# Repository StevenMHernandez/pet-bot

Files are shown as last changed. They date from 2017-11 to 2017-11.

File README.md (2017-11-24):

# Pet Bot

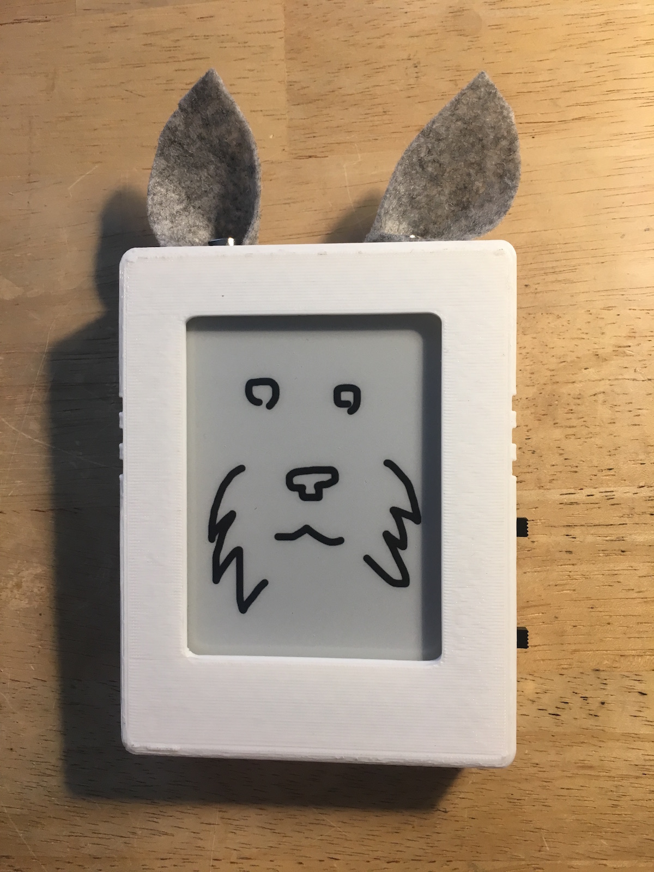
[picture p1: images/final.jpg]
Final pet


IoT connected pet bot connecting an E-ink display to an ESP8266 microcontroller connected through to the AWS IoT service.

Device Shadows are used in AWS IoT to model the ESP8266 when not connected to the network.
When connected, this allows the use of MQTT to transmit message from the server to the device and vice-versa.

Events (created through IFTTT) push data through an API Gateway to an AWS Lambda function to update the Device Shadow (Again through MQTT).

This repository contains:

* [3d models](3d) which were 3d printed in white
* [API Gateway/AWS Lambda functions](aws-lambda) used in the "serverless" backend
* [C++ code](src) used to program the microcontroller
* [Wiring schematics](schematic)
* [SD Card images](sdcard)
* [Network Diagram](network) for the whole system

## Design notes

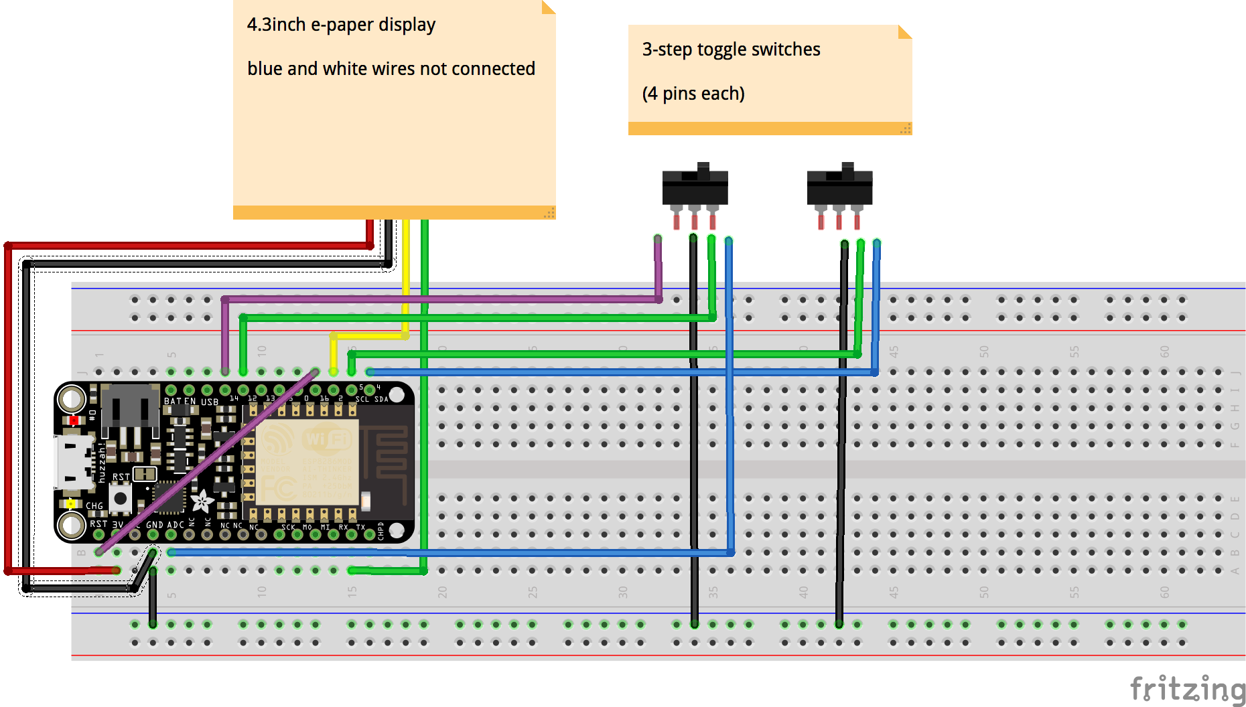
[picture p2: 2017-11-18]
schematic/layout_bb.png

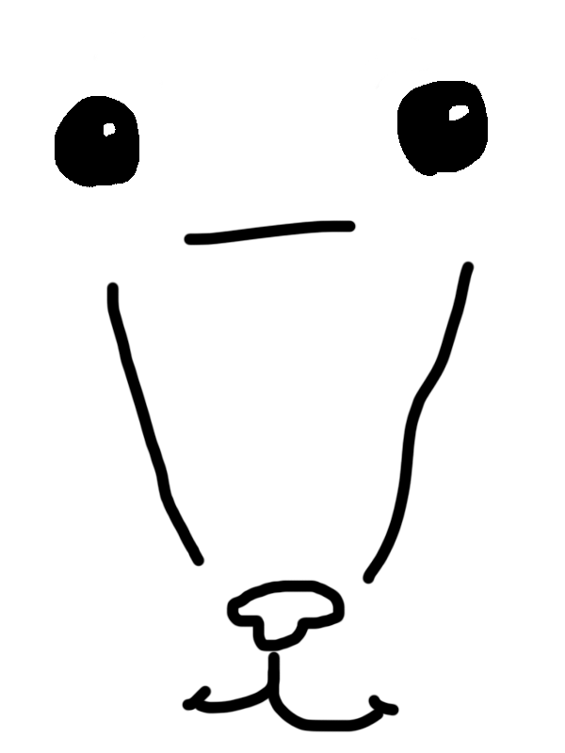
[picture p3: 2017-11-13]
sdcard/DOG20.BMP

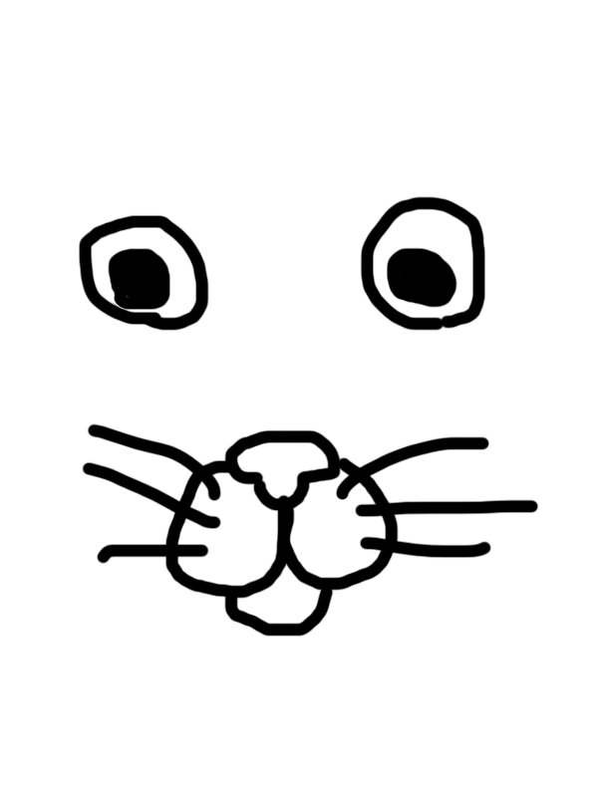
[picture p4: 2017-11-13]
sdcard/CAT00.BMP

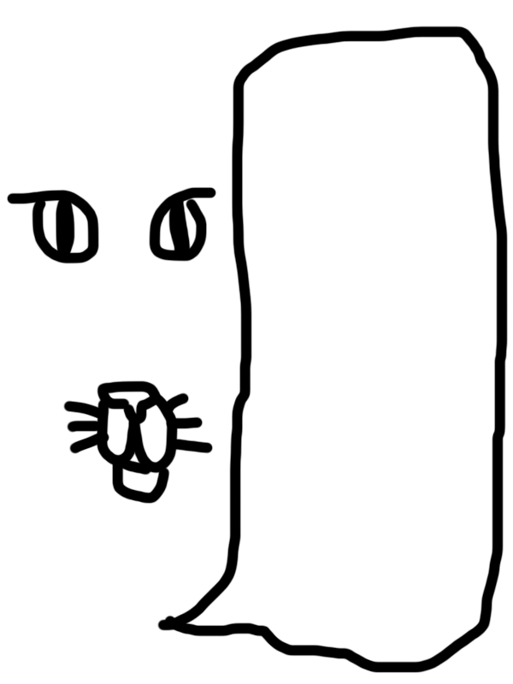
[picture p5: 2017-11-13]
sdcard/CAT11.BMP

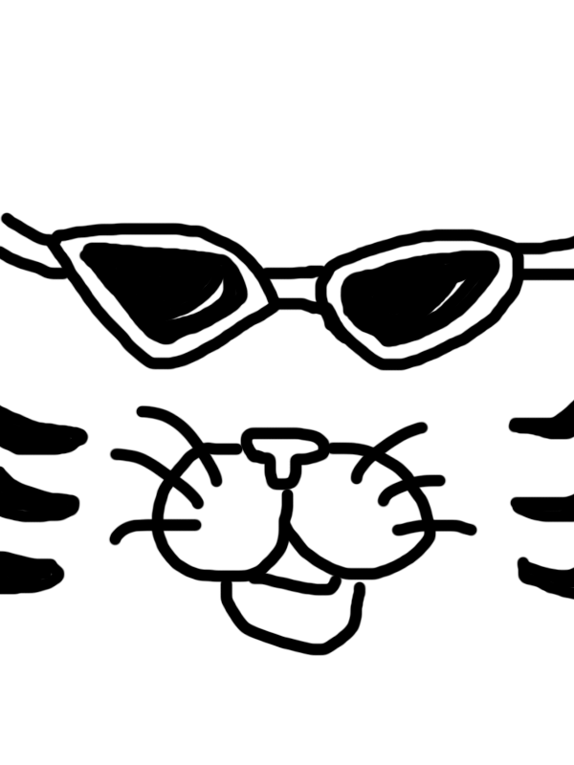
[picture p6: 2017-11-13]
sdcard/CAT20.BMP

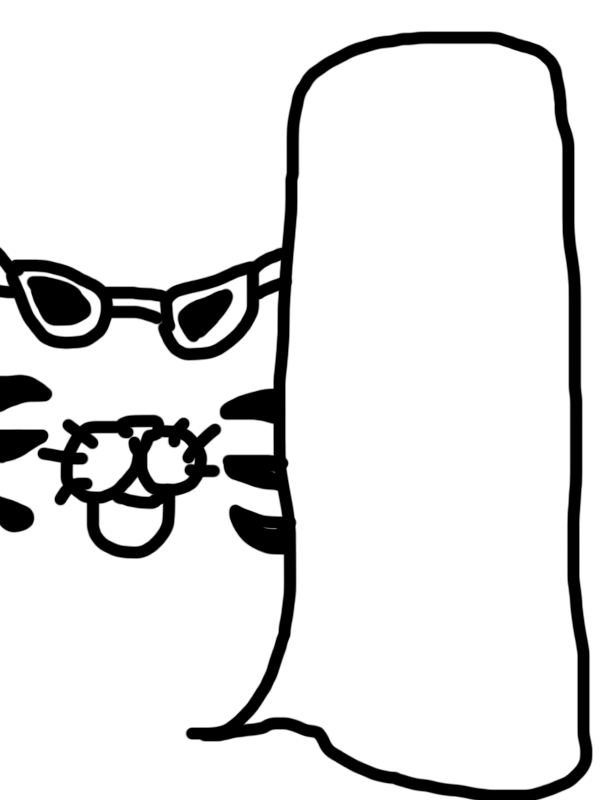
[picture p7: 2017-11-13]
sdcard/CAT21.BMP

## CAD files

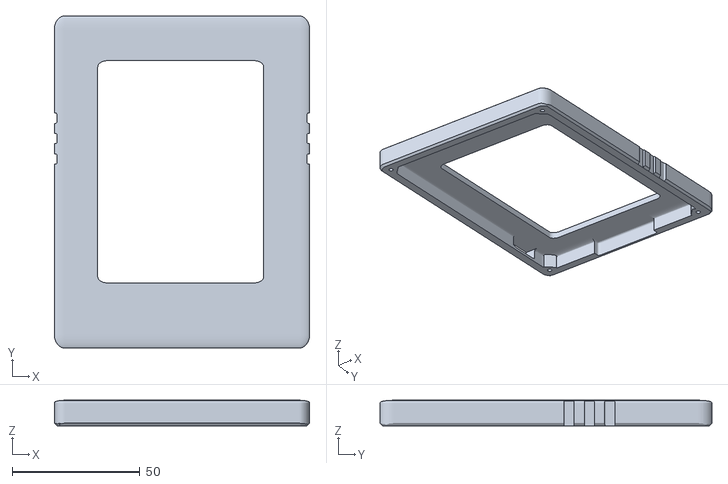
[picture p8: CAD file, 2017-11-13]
3d/front_enclosure.stl
100.0 x 130.0 x 10.00

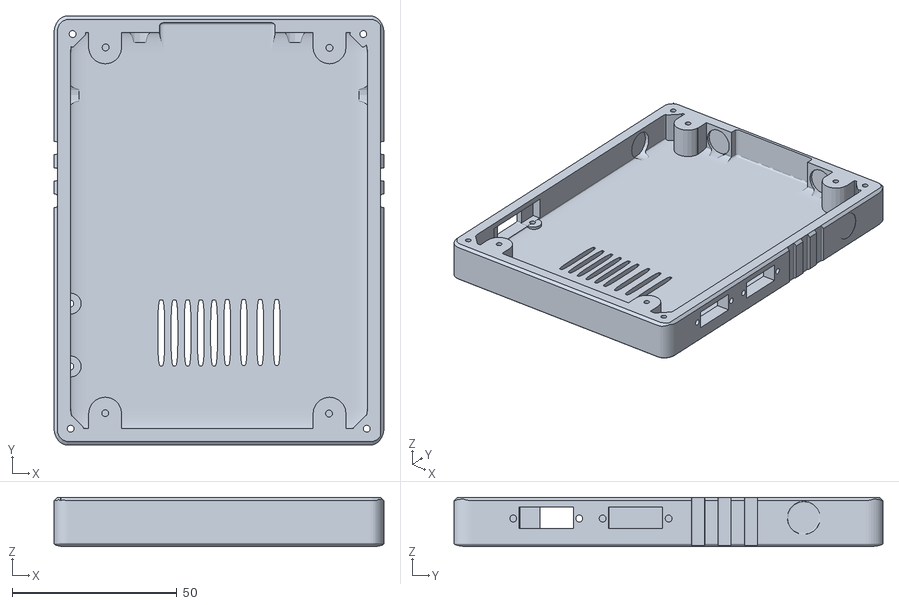
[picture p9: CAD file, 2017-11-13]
3d/back_enclosure.stl
100.0 x 130.0 x 15.0

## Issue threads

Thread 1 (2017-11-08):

Poll for messages

StevenMHernandez, 2017-11-08:
It seems that MQTT may not be a good option here for a battery powered device. There is rarely any new data published or received. Instead, polling will allow for deep sleep to conserve battery power.

StevenMHernandez, 2017-11-18:
Same as #2

Closed 2017-11-18.

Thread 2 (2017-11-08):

Deep sleep

StevenMHernandez, 2017-11-08:
Save power by automatically entering deep sleep mode

StevenMHernandez, 2017-11-16:
Connect pin 16 to reset.
Remove pin 16 connection from toggle switch (it is no longer needed)

Closed 2017-11-16.

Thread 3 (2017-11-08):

Toggles produce interrupts

StevenMHernandez, 2017-11-08:
To wake from sleep mode, we should also have interrupts on the pins used for the toggle switches

StevenMHernandez, 2017-11-16:
Unfortunately only the RESET pin can be used to leave deep sleep mode. Unfortunately, we can't create a simple logic gate with transistors to test for changes in the toggle switches. We are looking for rising edges, not boolean value.

So, we will not have interrupts here. Instead, we will just poll for value changes after leaving deep sleep.

Closed 2017-11-16.

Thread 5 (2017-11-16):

Display updates even when nothing changes after leaving deep sleep

StevenMHernandez, 2017-11-16:
We need to remember the screen values after exiting deep sleep.

`toggleChanged()` seems to be useless because the program resets to make this always evaluate to false.

StevenMHernandez, 2017-11-18:
This will be handled by checking the `delta` value of the device shadow from aws-iot

Closed 2017-11-18.

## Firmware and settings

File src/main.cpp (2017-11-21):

#include "Arduino.h"
#include <ESP8266WiFi.h>
#include <epd.h>
#include <aJSON.h>
#include "config.h"
#include "time.h"
#include "pin_mappings.h"
#include "bitmap_helpers.h"
#include "config/ConnectionParams.h"
#include "aws/ESP8266DateTimeProvider.h"

#define SHADOW_STATUS_REPORTED "reported"
#define SHADOW_STATUS_DESIRED "desired"

const char *AP_SSID = SSID_NAME;
const char *AP_PASS = SSID_PASS;

char *region = (char *) MY_AWS_REGION;
char *endpoint = (char *) MY_AWS_IOT_ENDPOINT;
char *mqttHost = (char *) MY_AWS_IOT_MQTT_HOST;
int mqttPort = MY_AWS_IOT_MQTT_PORT;
char *iamKeyId = (char *) MY_AWS_IAM_KEY_ID;
char *iamSecretKey = (char *) MY_AWS_IAM_SECRET_KEY;

ESP8266DateTimeProvider dtp;
AwsIotSigv4 sigv4(&dtp, region, endpoint, mqttHost, mqttPort, iamKeyId, iamSecretKey);
ConnectionParams cp(sigv4);
WebSocketClientAdapter adapter(cp);
MqttClient client(adapter, cp);

char filename[11];
uint32_t sleepTime = 30; // in minutes

void renderBitmap(int status) {
    epd_clear();
    epd_disp_string("loading...", 240, 750);
    epd_udpate();

    epd_clear();
    buildBitmapFileName(filename, status);
    epd_disp_bitmap(filename, 0, 0);

    if (status == STATUS_NO_MESSAGE) {
        epd_udpate();
    }
}

void setup_pins() {
    pinMode(TYPE_PIN_A, INPUT_PULLUP);
    pinMode(TYPE_PIN_B, INPUT_PULLUP);
    pinMode(TYPE_PIN_C, INPUT_PULLUP);

    pinMode(VARIANT_PIN_B, INPUT_PULLUP);
    pinMode(VARIANT_PIN_C, INPUT_PULLUP);
}

void setup_screen() {
    epd_set_memory(MEM_TF);
    epd_set_color(BLACK, WHITE);
    epd_screen_rotation(EPD_INVERSION);
    epd_set_en_font(GBK32);
}

void enter_sleep_mode(uint32_t minimum_sleep_time) {
    epd_enter_stopmode();
    if (sleepTime > 0) {
        ESP.deepSleep(sleepTime * SECONDS_PER_MINUTE * MICROSECONDS_PER_SECOND);
    } else {
        ESP.deepSleep(minimum_sleep_time);
    }
}

void update_thing_shadow(char *status, char *key, char *value) {
    aJsonObject *rootObj, *stateObj, *reportedObj;
    rootObj = aJson.createObject();
    aJson.addItemToObject(rootObj, "state", stateObj = aJson.createObject());
    aJson.addItemToObject(stateObj, status, reportedObj = aJson.createObject());
    aJson.addStringToObject(reportedObj, key, value);

    char *json = aJson.print(rootObj);
    client.publish("$aws/things/pet-test/shadow/update", json, 0, false);
    free(json);
}

void update_thing_shadow(char *status, char *key, int value) {
    aJsonObject *rootObj, *stateObj, *reportedObj;
    rootObj = aJson.createObject();
    aJson.addItemToObject(rootObj, "state", stateObj = aJson.createObject());
    aJson.addItemToObject(stateObj, status, reportedObj = aJson.createObject());
    aJson.addNumberToObject(reportedObj, key, value);

    char *json = aJson.print(rootObj);
    client.publish("$aws/things/pet-test/shadow/update", json, 0, false);
    free(json);
}

void update_thing_shadow(char *status, char *key, aJsonObject *value) {
    aJsonObject *rootObj, *stateObj, *reportedObj;
    rootObj = aJson.createObject();
    aJson.addItemToObject(rootObj, "state", stateObj = aJson.createObject());
    aJson.addItemToObject(stateObj, status, reportedObj = aJson.createObject());
    aJson.addItemToObject(reportedObj, key, value);

    char *json = aJson.print(rootObj);
    client.publish("$aws/things/pet-test/shadow/update", json, 0, false);
    free(json);
}

void setup_wifi_mqtt() {
    WiFi.begin(AP_SSID, AP_PASS);
    while (WiFi.status() != WL_CONNECTED) {
        delay(500);
    }

    int res = client.connect();

    if (res == 0) {
        update_thing_shadow((char *) SHADOW_STATUS_DESIRED, (char *) "type", getTypeName());
        update_thing_shadow((char *) SHADOW_STATUS_DESIRED, (char *) "variant", getVariantNumber());

        delay(100);

        client.subscribe("$aws/things/pet-test/shadow/get/accepted", 0, [](const char *topic, const char *msg) {
            // parse JSON, if there is a delta, update the screen
            aJsonObject *jsonObject = aJson.parse((char *) msg);
            aJsonObject *stateObject = aJson.getObjectItem(jsonObject, "state");
            aJsonObject *deltaObject = aJson.getObjectItem(stateObject, "delta");
            aJsonObject *desiredObject = aJson.getObjectItem(stateObject, "desired");
            aJsonObject *messageArray = aJson.getObjectItem(desiredObject, "message");
            aJsonObject *sleepTimeObject = aJson.getObjectItem(desiredObject, "sleepTime");
            sleepTime = sleepTimeObject->valueint;

            // Is there a delta? If so, we need to update the display
            // Otherwise, we are fine to sleep
            if (deltaObject != NULL && deltaObject->type != NULL && deltaObject->type == aJson_Object) {
                epd_clear();

                if (messageArray->type == aJson_Array && ((int) aJson.getArraySize(messageArray)) > 0) {
                    renderBitmap(STATUS_HAS_MESSAGE);

                    int totalHeight = 600;
                    int usedHeight = 50 * (int) aJson.getArraySize(messageArray);
                    int paddingTop = 100 + ((totalHeight - usedHeight) / 2);

                    int size = (int) aJson.getArraySize(messageArray);

                    for (int i = 0; i < size; i++) {
                        aJsonObject *m = aJson.getArrayItem(messageArray, (unsigned char) i);
                        epd_disp_string(m->valuestring, 330, paddingTop + (50 * i));
                    }

                    epd_udpate();
                } else {
                    renderBitmap(STATUS_NO_MESSAGE);
                }

                update_thing_shadow((char *) SHADOW_STATUS_REPORTED, (char *) "message", messageArray);
                update_thing_shadow((char *) SHADOW_STATUS_REPORTED, (char *) "type", getTypeName());
                update_thing_shadow((char *) SHADOW_STATUS_REPORTED, (char *) "variant", getVariantNumber());
                update_thing_shadow((char *) SHADOW_STATUS_REPORTED, (char *) "sleepTime", sleepTime);

                aJson.deleteItem(jsonObject);

                // The display takes about 20 seconds to refresh
                enter_sleep_mode(20 * MICROSECONDS_PER_SECOND);
            }
        });
    }
}

void setup() {
    Serial.begin(115200);

    setup_pins();
    setup_screen();
    setup_wifi_mqtt();

    // Request device shadow
    client.publish("$aws/things/pet-test/shadow/get", "{}", 0, false);

    // Receive device shadow (see lambda above)
    client.yield();

    // No display update, so we restart as soon as possible
    enter_sleep_mode(MICROSECONDS_PER_SECOND);
}

void loop() {
    // pass
}

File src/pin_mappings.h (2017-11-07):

#ifndef PT_PIN_MAPPINGS_H
#define PT_PIN_MAPPINGS_H

#define ONBOARD_LED 16

#define TYPE_PIN_A 14
#define TYPE_PIN_B 12
#define TYPE_PIN_C 17

#define VARIANT_PIN_A 16
#define VARIANT_PIN_B 5
#define VARIANT_PIN_C 4

#endif //PT_PIN_MAPPINGS_H

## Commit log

2017-11-01 added model for 3d printing
    [back_enclosure.stl, front_enclosure.stl]
2017-11-04 added eink display library, draw images (and text) onto screen, switch board to adafruit feather huzzah, added sd card images
2017-11-04 added schematics, update 3d model to slightly update enclosure design
    [back_enclosure.stl, front_enclosure.stl, layout.fzz]
2017-11-07 toggle switches are read to determine bitmap file names
2017-11-13 updated 3d print design, previous design did not leave enough room for some wires/switches, for the final product, I just cut into the the printed enclosure
    [back_enclosure.stl, front_enclosure.stl]
2017-11-13 change image depending on the toggle switch, added all images, display message when sent from AWS IoT
2017-11-16 enter deep sleep mode to lower power consumption from ~100-200 mAh to +/-10 mAh (it seems like this 10 mAh is from the display) closes #2
2017-11-18 use MQTT channels to read/set Thing Shadow for this device, update schematic to use pin 16 for reset after deep sleep closed #5
    [layout.fzz]
2017-11-20 store sleepTime in the deviceShadow of AWS IoT, allow for empty event.body to prevent AWS lambda execution from crashing
    [main.cpp]
